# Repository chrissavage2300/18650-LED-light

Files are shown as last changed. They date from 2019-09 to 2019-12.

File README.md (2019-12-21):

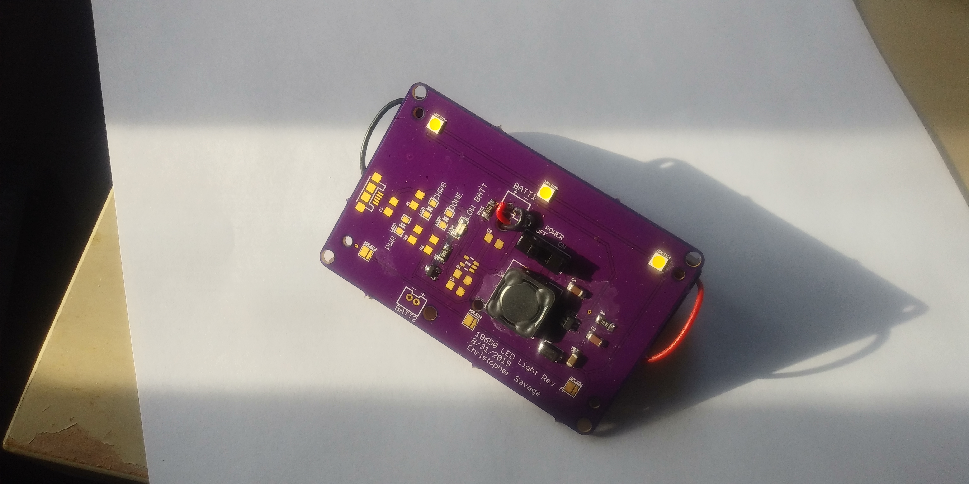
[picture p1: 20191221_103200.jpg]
Built

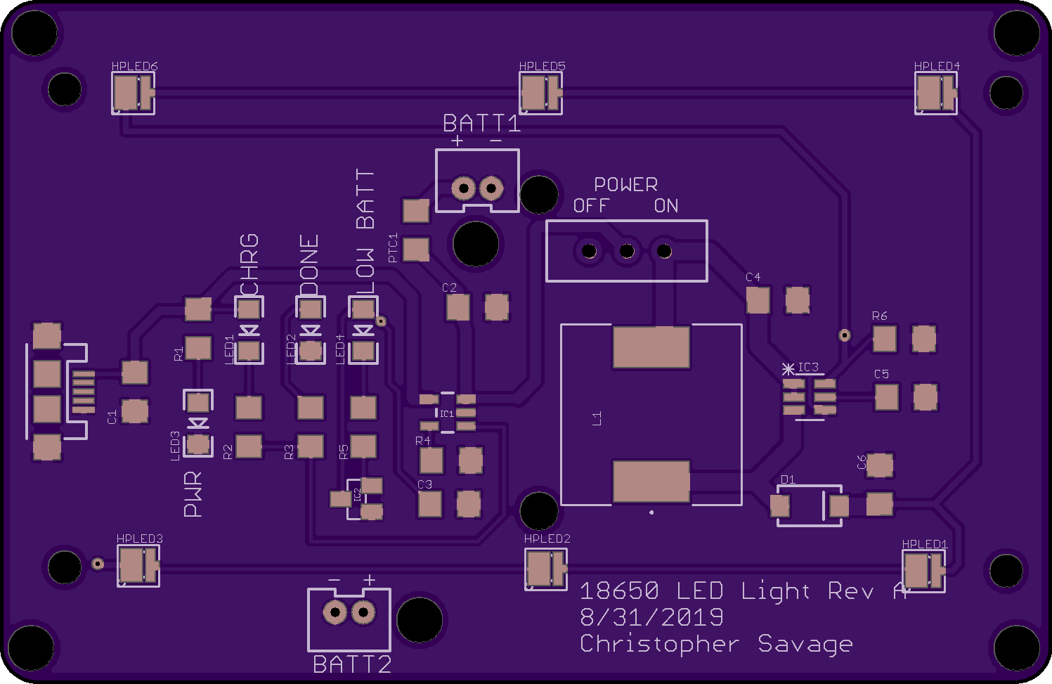
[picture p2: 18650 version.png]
oshboard

# 18650-LED-light
This is a high powered LED light powered by a 18650 Battery. 

* Uses Cree J Series Neutral white 3030 LED's.
* LED's Run at 150mA for double the amount of flux. They are connected in a 2P3S format. You can chose to solder one side or the other
* Features mounting holes for transparent 3D printed cover to scatter the light and protect the LED's
* Has Space for 2 18650 Lithium Batteries. I plan on reusing ones Ive salvaged which amount to around 1500mAh to 2000mAh.
* Run time at lowest setting (62mA for 1 string) should be 24 Hours using a 1500mAh Battery. This needs to be tested.
* 10 Hours at the brightest setting. 
* Has a built in USB charger with status LED's. Charge current is 500mA.

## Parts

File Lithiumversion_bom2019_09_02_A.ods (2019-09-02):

Part | Value | Device | Digikey
C1 | 4.7uf-10uf | CAP1206 | 1276-2730-1-ND (https://www.digikey.com/scripts/DkSearch/dksus.dll?Detail&itemSeq=259359212&uq=636605907311669960)
C2 | 4.7uf-10uf | CAP1206 | 1276-2730-1-ND (https://www.digikey.com/scripts/DkSearch/dksus.dll?Detail&itemSeq=259359212&uq=636605907311669960)
C3 | 100nf | CAP1206 | 490-6315-1-ND (https://www.digikey.com/scripts/DkSearch/dksus.dll?Detail&itemSeq=259359473&uq=636605914022700996)
C4 | 4.7uF | CAP1206 | 587-1336-1-ND‎ (https://www.digikey.com/product-detail/en/TMK316BJ475KL-T/587-1336-1-ND/931113/?itemSeq=302401443)
C5 | 220nF | CAP1206 | 445-14709-1-ND‎ (https://www.digikey.com/product-detail/en/C3216X5R2A224K115AA/445-14709-1-ND/3956375/?itemSeq=302401507)
C6 | 1uF | CAP1206 | 587-3371-1-ND‎ (https://www.digikey.com/product-detail/en/GMK316BJ105KLHT/587-3371-1-ND/4157503/?itemSeq=302401434)
D1 | MBRA120ET3G | DIODE-SCHOTTKY-B340A | MBRA120ET3GOSCT-ND‎ (https://www.digikey.com/product-detail/en/MBRA120ET3G/MBRA120ET3GOSCT-ND/2705026/?itemSeq=302464992)
HPLED1 | CREE_J_3030 | CREE_J_3030 | JB3030AWT-00-0000-000A0BD440ECT-ND‎ (https://www.digikey.com/product-detail/en/JB3030AWT-00-0000-000A0BD440E/JB3030AWT-00-0000-000A0BD440ECT-ND/9974532/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)
HPLED2 | CREE_J_3030 | CREE_J_3030 | JB3030AWT-00-0000-000A0BD440ECT-ND‎ (https://www.digikey.com/product-detail/en/JB3030AWT-00-0000-000A0BD440E/JB3030AWT-00-0000-000A0BD440ECT-ND/9974532/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)
HPLED3 | CREE_J_3030 | CREE_J_3030 | JB3030AWT-00-0000-000A0BD440ECT-ND‎ (https://www.digikey.com/product-detail/en/JB3030AWT-00-0000-000A0BD440E/JB3030AWT-00-0000-000A0BD440ECT-ND/9974532/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)
HPLED4 | CREE_J_3030 | CREE_J_3030 | JB3030AWT-00-0000-000A0BD440ECT-ND‎ (https://www.digikey.com/product-detail/en/JB3030AWT-00-0000-000A0BD440E/JB3030AWT-00-0000-000A0BD440ECT-ND/9974532/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)
HPLED5 | CREE_J_3030 | CREE_J_3030 | JB3030AWT-00-0000-000A0BD440ECT-ND‎ (https://www.digikey.com/product-detail/en/JB3030AWT-00-0000-000A0BD440E/JB3030AWT-00-0000-000A0BD440ECT-ND/9974532/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)
HPLED6 | CREE_J_3030 | CREE_J_3030 | JB3030AWT-00-0000-000A0BD440ECT-ND‎ (https://www.digikey.com/product-detail/en/JB3030AWT-00-0000-000A0BD440E/JB3030AWT-00-0000-000A0BD440ECT-ND/9974532/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)
IC1 | MCP73831 | MCP73831 | MCP73831T-2ACI/OTCT-ND
IC2 | APX803L 3.08v | ADP160 | APX803S-31SA-7DICT-ND
IC3 | TPS61165DBVR | TPS61165DBVR | 296-27597-1-ND‎ (https://www.digikey.com/product-detail/en/TPS61165DBVR/296-27597-1-ND/2340765/?itemSeq=302276923)
JP3 | USB-MICROB | USB-MICROB | 609-4613-1-ND (https://www.digikey.com/scripts/DkSearch/dksus.dll?Detail&itemSeq=259359546&uq=636605916531771878)
L1 | SRR1240-150M | SRR1240-100M | SRR1240-150MCT-ND‎ (https://www.digikey.com/product-detail/en/SRR1240-150M/SRR1240-150MCT-ND/2127389/?itemSeq=302398892)
LED1 | RED | LED1206 | 732-4991-1-ND (https://www.digikey.com/scripts/DkSearch/dksus.dll?Detail&itemSeq=259359576&uq=636605918367175400)
LED2 | GRN | LED1206 | 732-4993-1-ND (https://www.digikey.com/scripts/DkSearch/dksus.dll?Detail&itemSeq=259359578&uq=636605918367185401)
LED3 | BLUE | LED1206 | 732-4993-1-ND (https://www.digikey.com/scripts/DkSearch/dksus.dll?Detail&itemSeq=259359578&uq=636605918367185401)
LED4 | YEL | LED1206 | 732-4994-1-ND (https://www.digikey.com/scripts/DkSearch/dksus.dll?Detail&itemSeq=259359598&uq=636605919203834421)
PTC1 |  | RESISTOR1206
R1 | 300 Ohm | RESISTOR1206 | 311-300FRCT-ND (https://www.digikey.com/scripts/DkSearch/dksus.dll?Detail&itemSeq=259359834&uq=636605927071835779)
R2 | 300 Ohm | RESISTOR1206 | 311-300FRCT-ND (https://www.digikey.com/scripts/DkSearch/dksus.dll?Detail&itemSeq=259359834&uq=636605927071835779)
R3 | 300 Ohm | RESISTOR1206 | 311-300FRCT-ND (https://www.digikey.com/scripts/DkSearch/dksus.dll?Detail&itemSeq=259359834&uq=636605927071835779)
R4 | 2k Ohm | RESISTOR1206 | 311-2.00KFRCT-ND (https://www.digikey.com/scripts/DkSearch/dksus.dll?Detail&itemSeq=259359863&uq=636605935013839227)
R5 | 300 Ohm | RESISTOR1206 | 311-300FRCT-ND (https://www.digikey.com/scripts/DkSearch/dksus.dll?Detail&itemSeq=259359834&uq=636605927071835779)
R6 | 1.33 Ohm | RESISTOR1206 | 311-1.30FRCT-ND‎, 311-3.00FRCT-ND‎, ‎311-.68LWCT-ND‎
S1 |  | SWITCH-SPDTKIT | 679-1854-ND‎ (https://www.digikey.com/product-detail/en/MMS1208/679-1854-ND/1795800/?itemSeq=302474288)
VBAT | 2.54mm 2 pin | M02JST-PTH-VERT
VBAT | 2.54mm 2 pin | M02JST-PTH-VERT

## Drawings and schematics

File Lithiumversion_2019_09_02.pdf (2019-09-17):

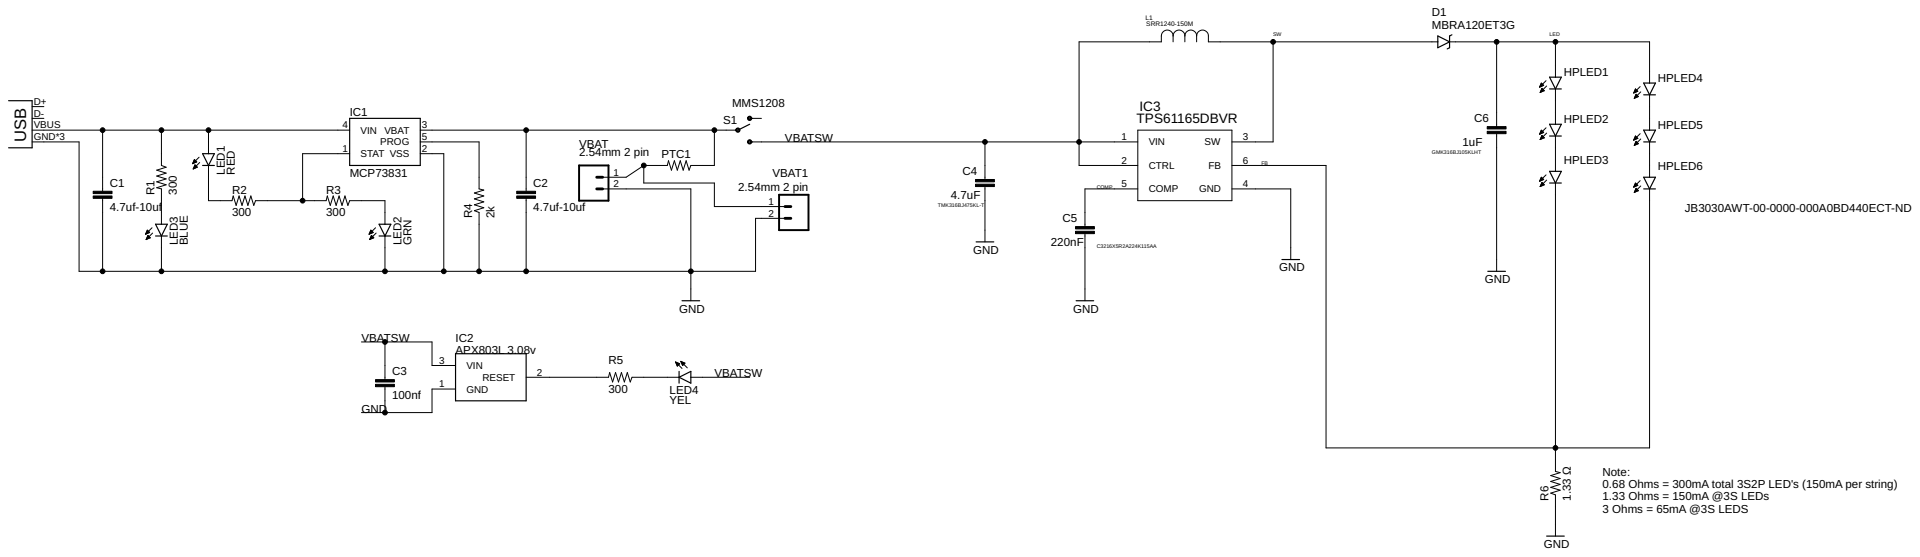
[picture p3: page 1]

Note: 0.68 Ohms = 300mA total 3S2P LED's (150mA per string)

1.33 Ohms = 150mA @3S LEDs 3 Ohms = 65mA @3S LEDS

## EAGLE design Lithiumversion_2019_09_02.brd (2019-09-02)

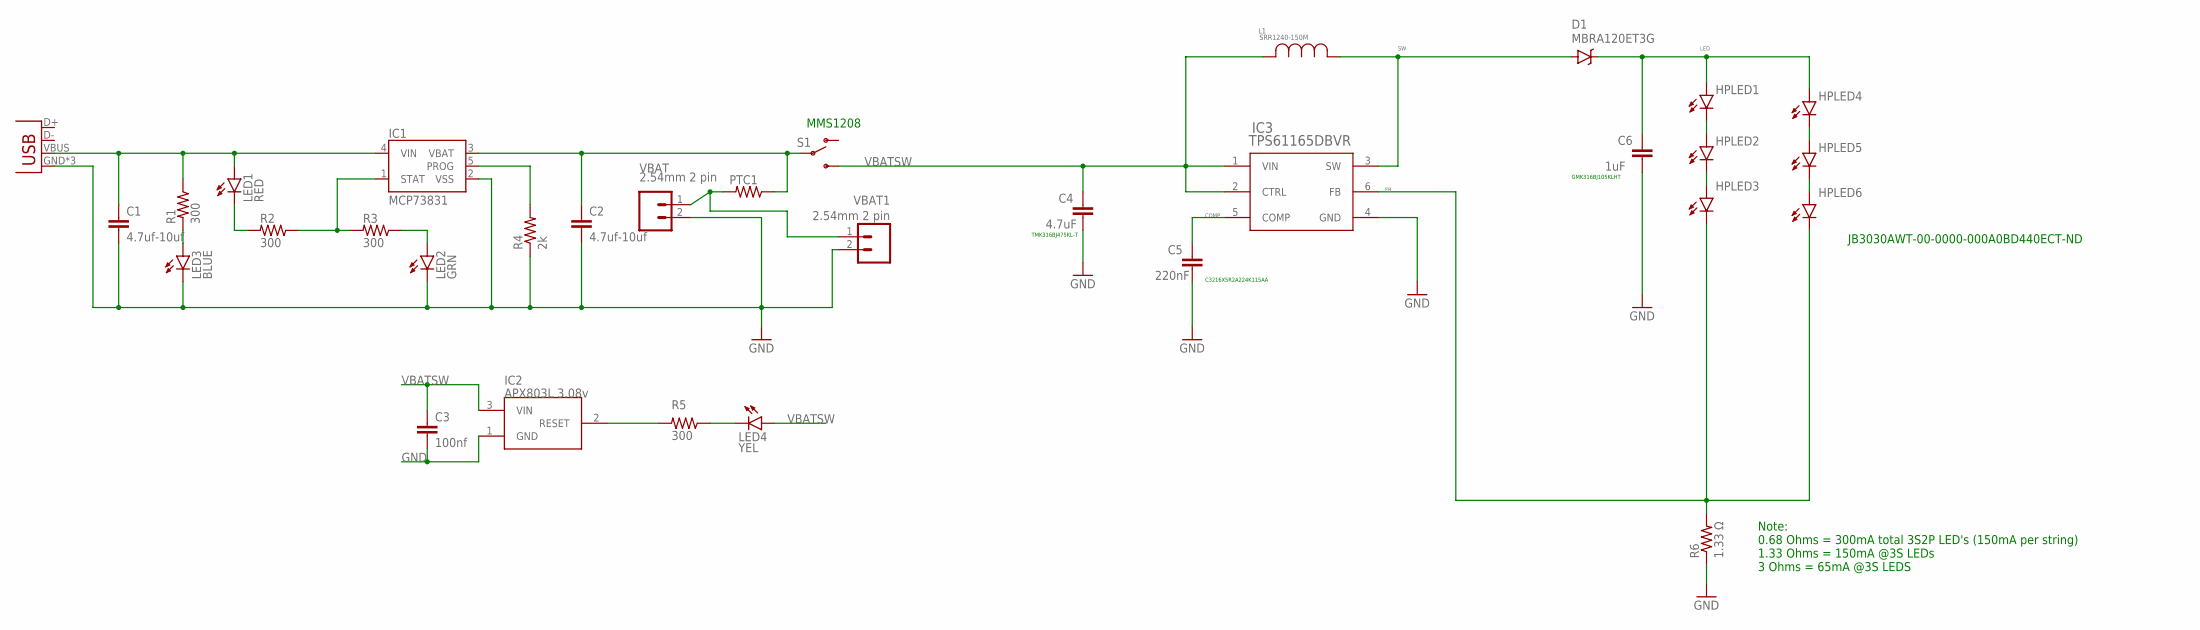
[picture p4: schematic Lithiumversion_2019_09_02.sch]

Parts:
C1, C2: 4.7uf-10uf; 1206
C3: 100nf; 1206
C4: 4.7uF; 1206
C5: 220nF; 1206
C6: 1uF; 1206
D1: MBRA120ET3G; SMA-DIODE
HPLED1, HPLED2, HPLED3, HPLED4, HPLED5, HPLED6: CREE_J_3030
IC1: MCP73831; SOT23-5
IC2: APX803L 3.08v; SOT23
IC3: TPS61165DBVR; DBV6
JP3: USB-MICROB
L1: SRR1240-150M; IND_BOURNS_SRR1240
LED1: RED; LED-1206
LED2: GRN; LED-1206
LED3: BLUE; LED-1206
LED4: YEL; LED-1206
PTC1: RESISTOR1206; 1206
R1, R2, R3, R5: 300; 1206
R4: 2k; 1206
R6: 1.33 Ω; 1206
S1: SWITCH-SPDTKIT; SWITCH-SPDT_KIT
VBAT, VBAT1: 2.54mm 2 pin; JST-2-PTH-VERT

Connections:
COMP: C5.2, IC3.5 (COMP)
FB: HPLED3.C, HPLED6.C, IC3.6 (FB), R6.2
GND: C1.2, C2.2, C3.2, C4.1, C5.1, C6.1, IC1.2 (VSS), IC2.1 (GND), IC3.4 (GND), JP3.GND, JP3.MT1 (GND), JP3.MT2 (GND), LED2.C, LED3.C, R4.1, R6.1, VBAT.2, VBAT1.2
LED: C6.2, D1.C, HPLED1.A, HPLED1.A2 (A), HPLED4.A, HPLED4.A2 (A)
unnamed: PTC1.2, VBAT.1, VBAT1.1
unnamed: LED1.C, R2.2
unnamed: IC1.1 (STAT), R2.1, R3.2
unnamed: IC1.5 (PROG), R4.2
unnamed: C1.1, IC1.4 (VIN), JP3.VBUS, LED1.A, R1.1
unnamed: LED2.A, R3.1
unnamed: IC2.2 (RESET), R5.2
unnamed: LED3.A, R1.2
unnamed: LED4.C, R5.1
unnamed: HPLED1.C, HPLED2.A, HPLED2.A2 (A)
unnamed: HPLED2.C, HPLED3.A, HPLED3.A2 (A)
unnamed: HPLED4.C, HPLED5.A, HPLED5.A2 (A)
unnamed: HPLED5.C, HPLED6.A, HPLED6.A2 (A)
SW: D1.A, IC3.3 (SW), L1.1
VBATSW: C3.1, C4.2, IC2.3 (VIN), IC3.1 (VIN), IC3.2 (CTRL), L1.2, LED4.A, S1.3 (S)
VCHARGE: C2.1, IC1.3 (VBAT), PTC1.1, S1.2

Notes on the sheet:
JB3030AWT-00-0000-000A0BD440ECT-ND
GMK316BJ105KLHT
‎TMK316BJ475KL-T‎
‎C3216X5R2A224K115AA‎
Note: 0.68 Ohms = 300mA total 3S2P LED's (150mA per string) 1.33 Ohms = 150mA @3S LEDs 3 Ohms = 65mA @3S LEDS
‎MMS1208‎

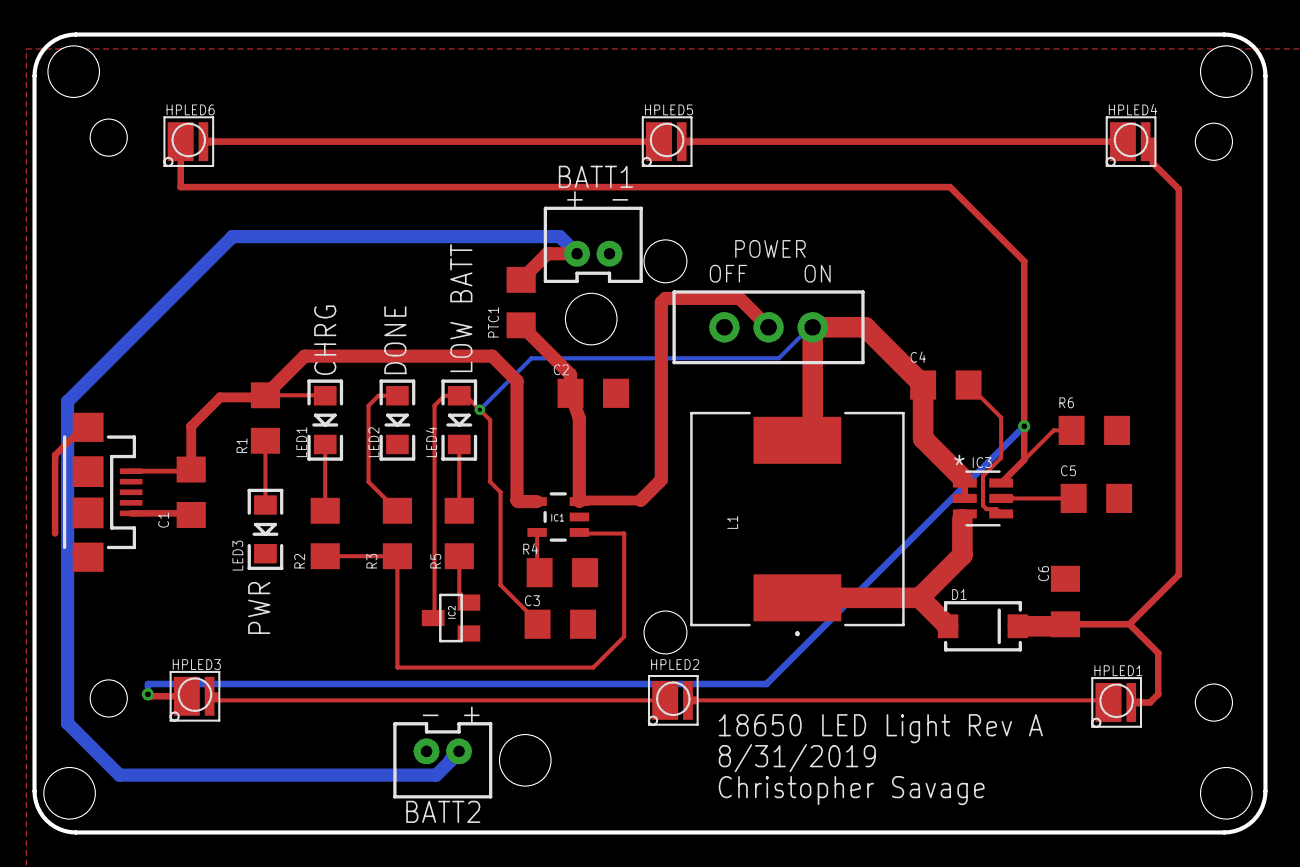
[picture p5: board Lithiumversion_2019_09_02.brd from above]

Board: 2 copper layers, 75.8 x 49.1 mm, 32 parts (0 on the bottom side), 20 nets.

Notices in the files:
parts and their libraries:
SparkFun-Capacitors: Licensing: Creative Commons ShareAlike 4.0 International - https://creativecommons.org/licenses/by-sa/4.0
